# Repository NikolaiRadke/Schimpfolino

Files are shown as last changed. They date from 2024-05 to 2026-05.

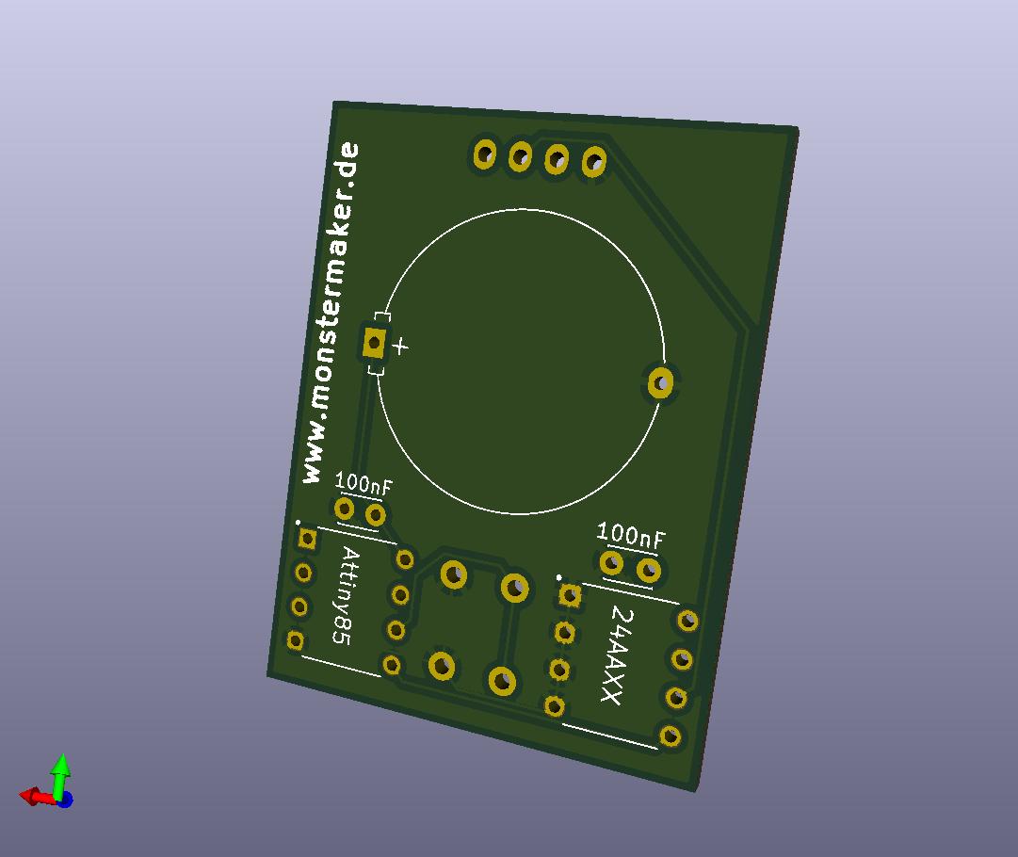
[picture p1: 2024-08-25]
schematics/Schimpfolino_back.jpg

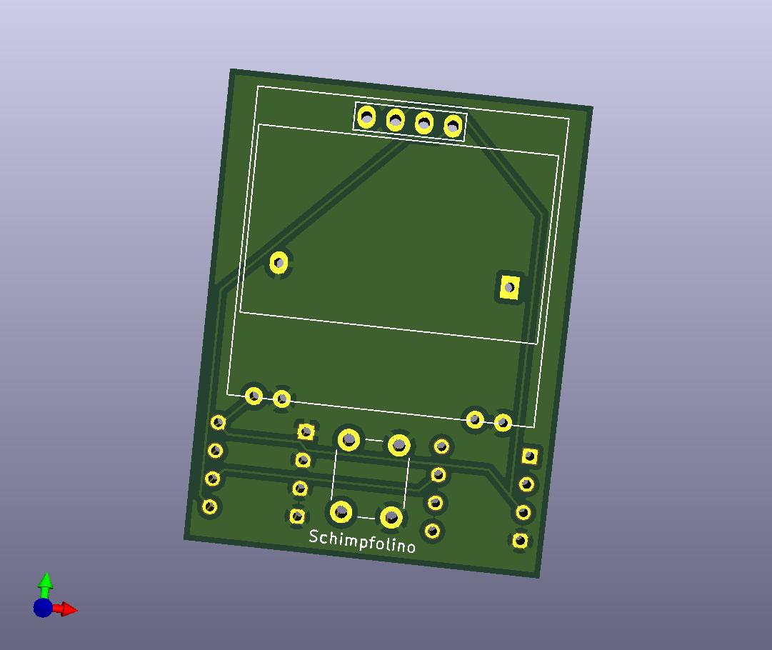
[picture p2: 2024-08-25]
schematics/Schimpfolino_front.jpg

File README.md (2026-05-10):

Schimpfolino

### "Klappriger Blubberfetzen" "Nervendes Riesenungemach" "Windige Pupswindel"  
    
Who doesn't like to be insulted? Schimpfolino is an evil gadget that always has a saying ready. Small, handy, power saving. And completely useless. You need a PCB and some parts listed below. It's easy to build and long lasting for everyday use. Insert battery, press the button and recieve your daily insult!        

*Huch, Englisch? Kann ich nicht. Schnell [hier hin](https://github.com/NikolaiRadke/Schimpfolino/wiki)*.  

Schimpfolino
  
Schimpfolino is a random curse word generator with **12.288.000** possible combinations right now. That should be enough for a while. It's suitable for children (but still evil), maintenance-free and the battery lasts for years. And with the right case, it's an evil monster, like the **Nokolino shaped** case below! Just press the button, receive an insult, after eight seconds it turns off again. That's it. Evil. You can print the case in black! Black is an evil color. It is so evil. It is so evil that it hurts many people that are good!

What's new?  
* **12.04.2026** Updaed ATTinyCore URL.  
    -- More news? See the [newsblog](https://github.com/NikolaiRadke/Schimpfolino/tree/main/NEWS.md).   

### Notes for non-German Schimpfolino makers  
  
The building wiki and the curse words are in German. You need English words? **Contribute!**  

### Prerequisites

Except for the tools and some time, you need:
* Arduino IDE 1.6.6 or higher
* ATTinyCore from Spence Konde  
* Serial terminal software like *CuteCom* (Linux) or *CoolTerm* (Linux/Windows/Mac).  
* Arduino UNO/Nano/Whatever with USB cable
* A breadboard
* Some Dupont wires
* A 10 µF capacitor
* (Optional a 2 kOhm resistor)  
  
And the following hardware:
* Schimpfolino PCB 
* ATtiny25/45/85 (ATtiny25 for V1.4)
* 24AA64 or larger EEPROM (up to 24AA512) - with an ATtiny85, no EERPOM is needed (V1.5).
* 0,96" SDD1306 (V1.0) or 0,96"/1,3" SDD1306/SH1106 I2C display (V1.3)  
* Button 6 x 6 mm, 9,5 mm height
* 2 DIP-8 sockets
* Batteryholder, 20 mm pin spacing
* CR2032 battery
* Double-sided adhesive pad, 25 x 15 x 3 mm
* (Optional 2 100 nF capacitors)  
  
### Content

```
Schimpfolino/
Root directory with some explanation files.  
|
├── case/
|   STL files to 3D print a case. Other kinds of hulls will follow.
|   ├── Boring/
|   |   Plain but smooth case by Michael Kussmaul.
|   ├── CuteVader/
|   |   Cute and evil case by falsanu.
|   └── Nokolino/
|       Standard Nokolino-shaped case.
|
├── python/
|   Schimpfolino as python script.
|
├── schematics/
|   The circuit diagram, PCB renderings and gerber files.
|
└── src/
    Firmware and word files.
    ├── eeprom/
    |   All you need to flash your EEPROM.
    |   ├── eeprom_writer/
    |   |   Arduino sketch to write to your EEPROM.
    |   ├── files/
    |   |   The EEPROM content word lists and the editor.
    |   └── files_new/
    |       EEPROM content vor new version (1.4)
    |
    ├── Schimpfolino/
    |   Standard sketch with libraries used in the Make article. (1.0)
    ├── Schimpfolino_new/ (1.5)
    |   Version for new improvments. Compatible to old version.
    ├── Schimpfolino_nopeeprom/ (1.0)
    |   Sketch for Schimpfolino without EEPROM.
    └── Schimpfolino_nopeeprom_new/ (1.5)
        New version. Compatible to old version.
```

### Let's get started!

Ready? Great! Let's start here: [German wiki](https://github.com/NikolaiRadke/Schimpfolino/wiki).  

## 💙 Support Schimpfolino

Schimpfolino is free and open source. If he saved your day, consider buying me a coffee! ☕




Every contribution helps keep this project alive! 🚀

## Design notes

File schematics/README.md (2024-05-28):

# Schematics

In this folder you can find the circuit diagram **Schimpfolino.pdf**, the PCB renderings and the gerber files to print your PCBs, with the unusual name **gerber.zip**. Upload the file to the PCB dealer of your choice or the dealer you trust and build your own Schimpfolino. Don't hesitate!

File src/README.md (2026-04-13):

# Firmware and tools for Schimpfolino

* **Schimpfolino**: a sketch for use with EEPROM only, for ATtiny45/85. Used in the Make article. For **ATtiny45/85**.   
* **Schimpfolino_noreeprom**: a hybrid sketch for use with or without EEPROM with reduced internal word list. For **ATtiny85 only**. Used in the Make article.  
* **Schimpfolino_new**: new version for new improvments and more supported displays. Compatible to old version. **Recommended**. For **ATtiny25/45/85**.
* **Schimpfolino_noeeprom_new**: Same as above but with a complete compressed internal word list. For **ATtiny85 only**.
* **eeprom/**: folder for files with EEPROM content and writing tool.
  
# Compiling instructions for Schimpfolino

In order to flash your ATtiny with the Schimpfolino sketch, you need the **Arduino-IDE** (1.6.6 or higher), with installed **ATtiny-support** and an **Arduino** connected to your microcontroller.

### Preparing the IDE  
 
1. Open ``` File > Preferences ```.  
2. Find the field ``` Additional Boards Manager URLs ```.  
3. Enter ``` https://drazzy.com/package_drazzy.com_index.json ```.  
4. Press ``` OK ```.  
5. Open ``` Tools > Board > Boards Manager ```.  
6. Select ``` ATTinyCore by Spence Konde ```.  
7. Press ``` Install ```.

> [!NOTE]
> The installation of ATTinyCore often results in an error.  
> See [ATTinyCore GitHub](https://github.com/SpenceKonde/ATTinyCore/blob/v2.0.0-devThis-is-the-head-submit-PRs-against-this/Installation.md) for manual installation Instructions.

### Peparing your Arduino  

1. Connect your Arduino to your system.  
2. Open ``` File > Examples > ArduinoISP > ArduinoISP ```.  
3. Upload the sketch.

### Connecting your ATtiny with the Arduino  

1. Disconnect your Arduino.
2. Connect your ATtiny as seen below.
3. Add the 10 uF capacitor.    
  
ATTINY-ARDUINO  
  
### Burning an ATtiny bootloader  
  
Technically, this process will flash no bootloader, the IDE just sets the fuses. 
  
1. Connect your Arduino to your system again.  
2. Select ``` Tools > Programmer > Arduino as ISP ```.  
   For the **UNO R4** choose ``` Tools > Programmer > Arduino Leo/Micro as ISP (ATmega32U4) ```. 
4. Select ``` Tools > Board > ATTinyCore > ATtiny25/45/85 (No bootloader) ```.
5. Select ``` Tools > Port ``` for the matching port.  
6. Select ``` Tools > B.O.D. Level [...] > B.O.D. Disabled (saves power) ```.
7. Select ``` Tools > Chip > ATtiny85 ``` or ``` Tools > Chip > ATtiny45 ``` or ``` Tools > Chip > ATtiny25 ```.
8. **For V1.X**: Select ``` Tools > millis()/micros() > Disabled (saves flash) ```.
9. Start burning process with ``` Tools > Burn bootloader ```.  

Now you can flash your ATtiny with any sketch you want! But this time, we focus on Schimpfolino.   

### Flashing and configuring Schimpfolino firmware
  
1. Open the Schimpfolino sketch.
2. If you want a bold font, uncomment ``` #// define bold ``` in **oled.h** by removing ``` // ``` (Only V1.X).     
3. Select ``` Sketch > Upload using programmer ``` (IDE 2.X) or press upload button (IDE 1.X and 2.3.3 or newer). 
4. DONE.  

Now you can remove the microcontroller and plug it into the socket of your Schimpfolino.  

## Hints for Linux users  

With some Debain-based distributions like Ubuntu or Mint you might recieve an error while trying to upload your sketch to the ATtiny like  
``` avrdude: ser_open(): can't open device "/dev/ttyUSB0": Permission denied ```.  
This issue can be solved by adding your user to the dialout-group. Open a terminal and type  
``` sudo usermod -a -G dialout $USERNAME ```.  
Enter your password and restart. Now it should work.  

If not: Maybe you are using an **Arduino Nano clone** with **CH340 chip**, the IDE may not find your port. This is because of a conflict with the preinstalled Braille driver. If you don't need it, deinstall the driver with  
``` sudo apt-get remove brltty ```  
and the IDE should find the port after reboot now.

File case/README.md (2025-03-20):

# Case

Schimpfolino is pretty small and handy and works without a hull, fur or case. But if you want a special design, you will find some ideas here:

## Nokolino
Schimpfolino_NokolinoSchimpfolino_Nokolino  

A Nokolino-shaped case for 3D printing.  
* **Schimpfolino_Case_Nokolino.stl** - the case  
* **Schimpfolino_Case_Nokolino_Cover.stl** - the cover

## Boring
Schimpfolino BoringSchimpfolino_BoringSchimpfolino_BoringSchimpfolino_Boring  

A plain but smooth 'boring' case by Michael Kussmaul.
Needs a 30 mm acrylic glass scrreen protection and a no light, 12 mm flat head, stainless or black shell button.  
* **Schimpfolino_Case_Boring.stl** - the case  
* **Schimpfolino_Case_Boring_Cover.stl** - the cover
* **Schimpfolino_Case_Boring_Display_Holder.stl** - the display holder  
* **Schimpfolino_Case_Boring_Inset.stl** - fot the additional screen protection

## Cute Vader
Schimpfolino_NokolinoSchimpfolino_Nokolino  

A small but incredible evil case by Jan Fanslau. GitHub: [falsanu](https://github.com/falsanu)  
* **Schimpfolino_Case_CuteVader.stl** - the case
* **Schimpfolino_Case_CuteVader_Cover.stl** - the cover
   
## More cases and suits will follow. Stay tuned!

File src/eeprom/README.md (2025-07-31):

# Setting up a serial connection and writing to EEPROM

You need:  
* Sketch **eeprom_writer.ino**.
* An Arduino Uno/Nano/Whatever.
* A serial terminal like *CoolTerm* (Linux/Windows/Mac) or *CuteCom* (Linux).

### Connecting your Arduino with the EEPROM

1. Disconnect your Arduino.
2. Connect your Arduino with the EEPROM as seen below. It is an **I2C** connection. If you want to use any other board, connect **SDA** with **pin 5** and **SCL** with **pin 6** of your EEPROM.
   
EEPROM with Arduino

**Wait!** Where is the **pull up resistor**?  
Yes indeed, I2C needs a pull up resistor, **2 kOhm** between **SDA** and **VCC**. But: The Arduino has an internal **20 kOhm** pull up resistor at every I/O pin. These are pulled up with every I2C connections when the standard library **Wire.h** is used. This is not the correct value but works reliable with slow connections. This is a very slow connection. But if you are unsure, add an externel pull up resistor. Schimpfolino's display finally has the missing resistors on board. 
  
For the **UNO R4** (Wifi), the pull up resistor is mandatory!

### Flashing the content

1. Connect the Arduino to your computer.  
2. Open the Schimpfolino writer sketch **eeprom_writer.ino** in the Arduino IDE and upload the sketch. 
3. Start your favorite serial terminal, set to **9600 Baud, 8-N-1** and a **5 ms delay** after each character, no Linefeed (LF) oder Carriage Return (CR). 
4. Open the connection to the port (COM? in Windows, see device manager or IDE | /dev/ttyACM0 for Arduino Uno or /dev/ttyUSB? other Arduinos in Linux)
5. The Arduino will tell you through the serial terminal, what eeprom_writer is doing. Now upload the files **eeprom1.txt** to **eeprom5.txt**. Use folder **files_new** for >= V1.4 or **files** for older versions.  
6. Close the connection and remove the EEPROM.
  
## Structure of eeprom?.txt files

Each file contains a set of words. Each word has **10** characters, spaces are mandatory! Just write them one after another. The EEPROM writing sketch will calculate their number and store both number and words into the EEPROM. The last character of the file has to be a **!**. You need a text editor. An office word processor will not work.  

German **Umlaute** must be converted:  
**ä** -> **[** | **ö** -> **]** | **ü** -> **^** | **ß** -> **_** | **Ä** -> **{** | **Ö** -> **|** | **Ü** -> **}**  
Versions <= V1.3:
**ä** -> **#** | **ö** -> **$** | **ü** -> **%** | **ß** -> **|** | **Ä** -> **&** | **Ö** -> **'** | **Ü** -> **(**
  
There is an (beta) offline editor **eeprom.html** in the files and files_new folders. You can easily add new words or generate a new eeprom?.txt. Umlaute will be converted and spaces and the terminating ! added automatically.

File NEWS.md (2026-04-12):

# Newsblog

## 2026

* **12.04.2026** Updaed ATTinyCore URL.  
* **07.01.2026** Release v1.5 with better text editor and much improved noeeprom version.  

## 2025

* **04.08.2025** Schimpfolino python script added.
* **31.07.2025** Added hints for using the **UNO R4**.  
* **15.05.2025** Firmware **1.X-150525** once again with smaller flash size. The **noeeprom** variants got 5 more words.  
* **08.05.2025** Release **V1.4** with reduced flash size and ATtiny25 support or more words in internal wordlists.  
* **08.05.2025** Firmware **1.4-070525** with more reduced size. **Schimpfolino_new.ino** finaliy fits into an ATtiny25! New EERPOM files needed!  
* **03.05.2025** Firmware **1.X-030525** again with even bigger optimizations: 10 more words for both _noeeprom.ino**.  
* **15.04.2025** Firmware **1.X-150425** with bigger code optimizations: 20 more words for **schimpfolino_noeeprom.ino** and 30 new words for **schimpfolino_noeeprom_new.ino**.  
* **07.04.2025** Firmware **1.X-070425** with code optimizations. One day, it will fit into an ATtiny25... 
* **27.03.2025** Check out Maker Faire Ruhr Dortmund with Schimpfolino-Kits available at the heise shop an **Schimpferator**, the XXL-Schimpfolino!   
* **30.03.2025** Added new 'CuteVader' case by [falsanu](https://github.com/falsanu)     
* **13.03.2025** Release **V1.3** with a bugfix and improvements.  
* **13.03.2025** Firmware **1.01-130325** with fix for long words and **1.3-130325** with fix and now full 1.3" support.   
* **20.02.2025** Updated **eeprom_writer** with check for last written word.  
* **16.01.2025** Release **V1.2.2** with final text centering method.  
* **16.01.2025** Firmware **1.01-160225** and **1.22-160125** with, finally, perfect text centering :-)  
  
## 2024

* **28.12.2024** Release **V1.2.1** with the new case and a fix for SH1106 displays.  
* **28.12.2024** Added new 'boring' but smooth case by [Michael Kussmaul](https://github.com/kusmi).  
* **24.12.2024** Firmware **1.X-241224** Increased OLED init time for more compatibility.   
* **07.11.2024** Firmware **1.2-071124** with external wordlist for **Schimpfolino_nooeeprom_new.ino**. 
* **05.11.2024** Firmware **1.X-051124** with fixed text centering. Finally!      
* **30.10.2024** Firmware **1.2-391024** with heavy shrunk (and crippled) libraries.    
* **29.10.2024** Release **V1.2** with enough new features to justify it.   
* **29.10.2024** **V1.2** with optional bold font. **1.2-291024**.  
* **26.10.2024** **V1.1** now with full SH1106 support. **1.1-271024**.    
* **26.10.2024** **1.03-261024** now supports SH1106 displays. Thanks to Sebastian Völkel.  
* **21.10.2024** Firmware **1.02-201024**. Switched to Tiny-I2C library and freed 600 bytes. Schimpfolino_new_eeprom now has 5 x 15 more words.  
* **19.10.2024** Firmware **1.0x-191024**. Fixed the noeeprom bug and removed the workaround. Finally. Pew.  
* **18.10.2024** Firmware **1.01-181024** for the *new* versions is working now. **Schimpfolino_noeeprom_new.ino** got 5 x 5 new words.  
* **17.10.2024** Release **V1.0M fixed**: important for Schimpfolino_noeeprom.ino **with** EEPROM and small further optimizations.  
* **16.10.2024** Small optimization and **Schimpfolino_noeeprom.ino** is working correctly again! Pew! **1.0x-161024**.  
* **11.10.2024** Better helping variable handling. Won 16 bytes! Worth an update? Yes, of course! **1.01-111024** and **1.0-111024**.  
* **10.10.2024** New sketches added. **1.01-101024** with removed millis(): 182 bytes saved. Old versions are for the Make article but the new 1.01 versions are compatible.  
* **19.08.2024** Release **V1.0M** - (M for Make Magazie) Schimpfolino seems to be finished! Well... for now ;-)   
* **05.08.2024** Big Umlaute are supported. **1.0-050924**.
* **24.08.2024** Slightly flash usage improvements. **1.0-290824**.  
* **24.08.2024** Schimpfolino is now using a **24AAXX** EEPROM to save more power. No changes in the code needed.  
* **10.08.2024** Code of Conduct was added.
* **07.08.2024** Final PCB design was uploaded.  
* **13.07.2024** Optimized power management and prepared firmware for new coming board. **1.0-130724**.
* **10.07.2024** Halfed idle power draw. **1.0-100724**.  
* **10.07.2024** Better random numnner generator. Small and reliable.
* **09.07.2024** Better individual random seed. **1.0-090724**.
* **05.07.2024** Set open ports to INPUT_PULLUP to prevent floating. **1.0-050724**.
* **27.06.2024** eeprom_writer now waits for EEPROM connection.
* **26.06.2024** Added hints to pull up resistors when using the EEPROM with Arduino.  
* **18.06.2024** The **EEPROM Editor** has been improved.  
* **16.06.2024** An **EEPROM Editor** for the word list files was added.  
* **14.06.2024** Optimized code and finished **Schimpfolino_noeeprom**. Both are **1.0-140624** now.
* **13.06.2024** Added **TODO.md** - everyone needs a ToDo list!  
* **13.06.2024** (Slighty) better text centering and higher display contrast. **1.0-130624**. 
* **12.06.2024** Big SSD1306 rework. Version is now **1.0-120624**. 
* **11.06.2024** **Schimpfolino_wire** is now ***Schimpfolino**. TinyWireM is not needed anymore.
* **07.06.2024** Added alternative firmware **Schimpfolino_wire** with version **1.0-070624**  
* **07.06.2024** Updated **Schimpfolino** to **1.0-070624** with small libary cleanups.  
* **07.06.2024** Switched to ATTinyCore. It's much more modern, builds smaller binaries and has tons of features.  
* **29.05.2024** Schimpfolino got his first release!  
* **28.05.2024** Finished the German wiki! Schimpfolino is ready to release.
* **26.05.2024** Finished the last README files! The repository is almost ready. 
* **25.05.2024** The case cover fits perfectly!
* **24.05.2024** New Nokolino shaped case model.
* **23.05.2024** Renamed source files. The main file with eeprom ist now **Schimpfolino.ino**.
* **22.05.2024** Reworked EEPROM content structure and adjusted text centering. **1.0-220524**.  
* **20.05.2024** schimpfolino_eeprom: text is now centered. Version is **1.0-200524**.  
* **17.05.2024** Opened the Schimpfolino repository.
* **17.05.2024** Latest release of **schimpfolino_eeprom** to **1.0-090524**.
* **17.05.2024** Latest release of **schimpfolino** to **1.0-050524**.
* **17.05.2024** Latest release of **eeprom-writer** to **1.0-090524**.

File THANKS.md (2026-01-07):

# Thanks

These people helped me with Schimpfolino:  
  
 - **Elise Lindner** - finding funny words.
 - **Elisabeth Seidl** - graphics. 
 - **[falsanu](https://github.com/falsanu)** - the 'CuteVader' case, filament and some ideas.
 - **Marcus Hansson** - the great articles in the German Make Magazin.
 - **[MDecker](https://github.com/MDecker-MobileComputing)** - spelling corrections.
 - **Sebastian Völke** - SH1106 support and bold font.
 - **Birger Töpelmann** - wordlist ideas.
 - **Michael Kussmaul** - solving an annoying display issue and the 'Boring' case.
 - **Tilman Beck** - hints für using the UNO R4.
 - **Markus Fölling** - better EEPROM files editor.  
 - **Make Magazin** - publishing three articles.  
  
Used ressources:  
  
- **Arduino IDE 2.3.4** - [Arduino](http://www.arduino.cc)  
- **ATTinyCore** - [GitHub](https://github.com/SpenceKonde/ATTinyCore)
- **SD1306_nimimal library** - [GitHub](https://github.com/kirknorthrop/SSD1306_minimal)
- **Tiny-I2C library** (V1.X) - [GitHub](https://github.com/technoblogy/tiny-i2c)  
- **CuteCom 0.30.3** - [Sourceforge](https://cutecom.sourceforge.net/)
- **KiCad 8.0** - [KiCad](https://www.kicad.org)
- **Tinkercad** - [Tinkercad](https://www.tinkercad.com)
- **Cura 5.7.1** - [UltiMaker](https://ultimaker.com/de/software/ultimaker-cura)
- **Inkscape 1.1** - [Inkscape](https://inkscape.org)
- **Gimp 2.10.32** - [Gimp](https://www.gimp.org)
- **Fritzing 0.9.6** - [Fritzing](https://fritzing.org)  
- **ChatGPT** - [OpenAI](https://chatopenai.de/)

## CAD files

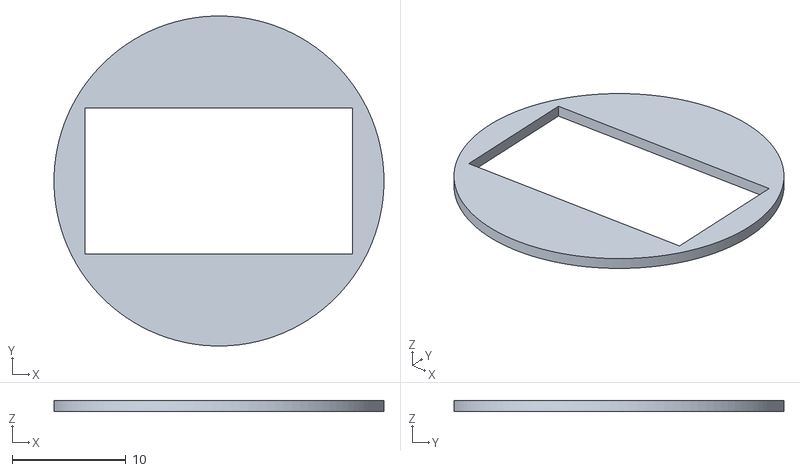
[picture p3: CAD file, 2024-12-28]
case/Boring/Schimpfolino_Boring_Inset.stl
29.0 x 29.0 x 1.00

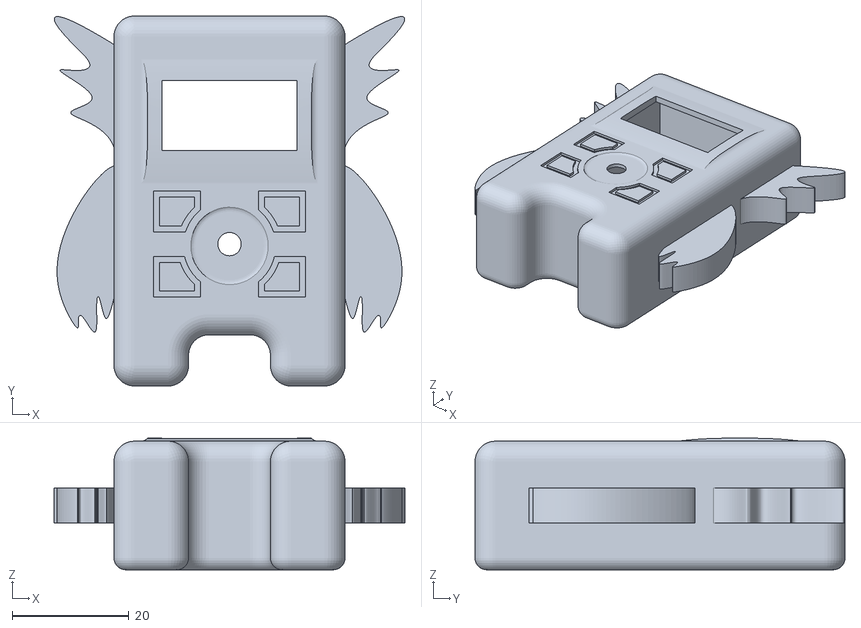
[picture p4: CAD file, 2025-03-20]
case/CuteVader/Schimpfolino_Case_CuteVader.stl
59.9 x 63.3 x 22.5

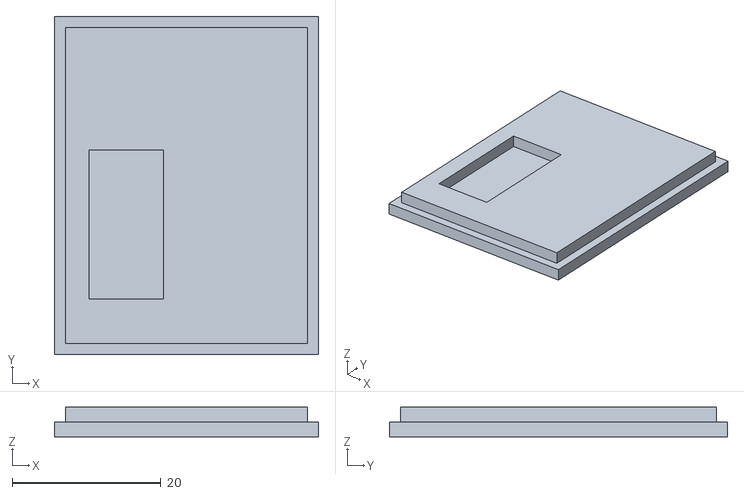
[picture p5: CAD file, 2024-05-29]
case/Nokolino/Schimpfolino_Case_Nokolino_Cover.stl
35.5 x 45.5 x 4.00

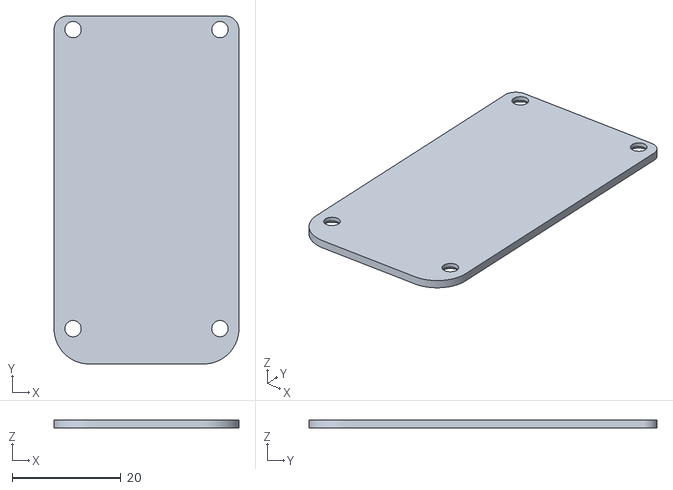
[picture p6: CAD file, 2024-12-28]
case/Boring/Schimpfolino_Boring_Cover.stl
34.0 x 64.0 x 1.50

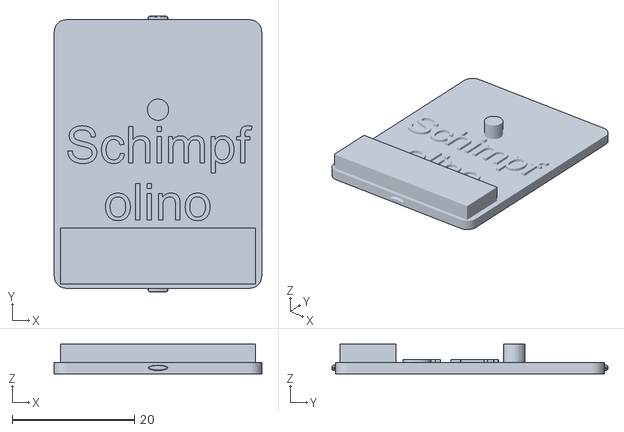
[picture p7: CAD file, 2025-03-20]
case/CuteVader/Schimpfolino_Case_CuteVader_Cover.stl
34.0 x 45.2 x 4.90

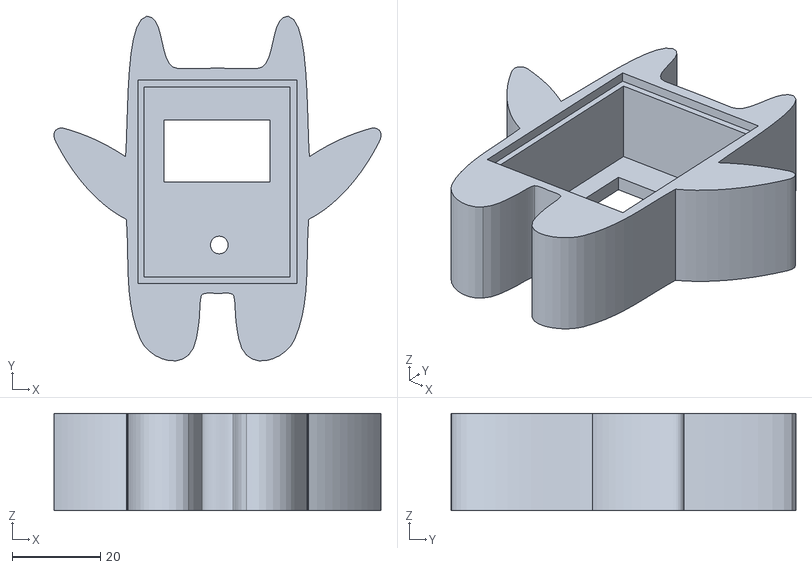
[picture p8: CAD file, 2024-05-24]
case/Nokolino/Schimpfolino_Case_Nokolino.stl
74.0 x 78.0 x 22.0

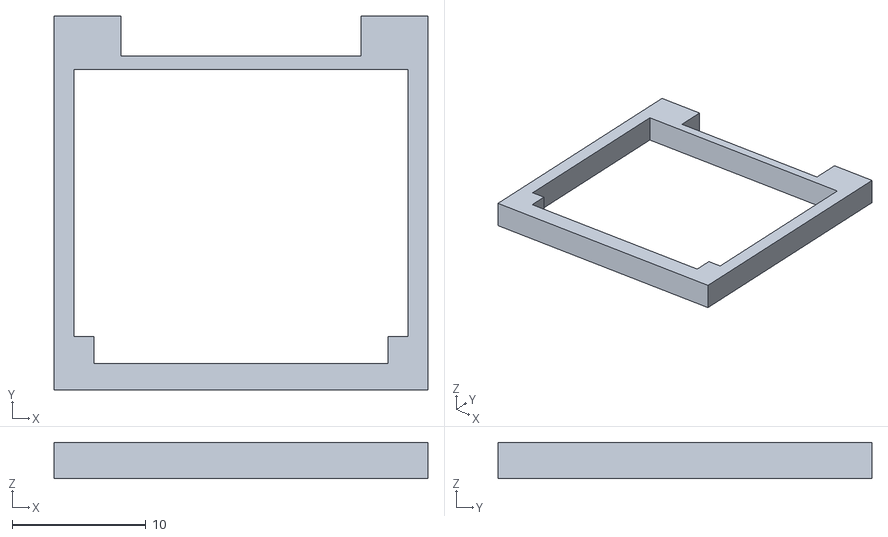
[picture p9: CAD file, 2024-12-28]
case/Boring/Schimpfolino_Boring_Display_Holder.stl
28.0 x 28.0 x 2.70

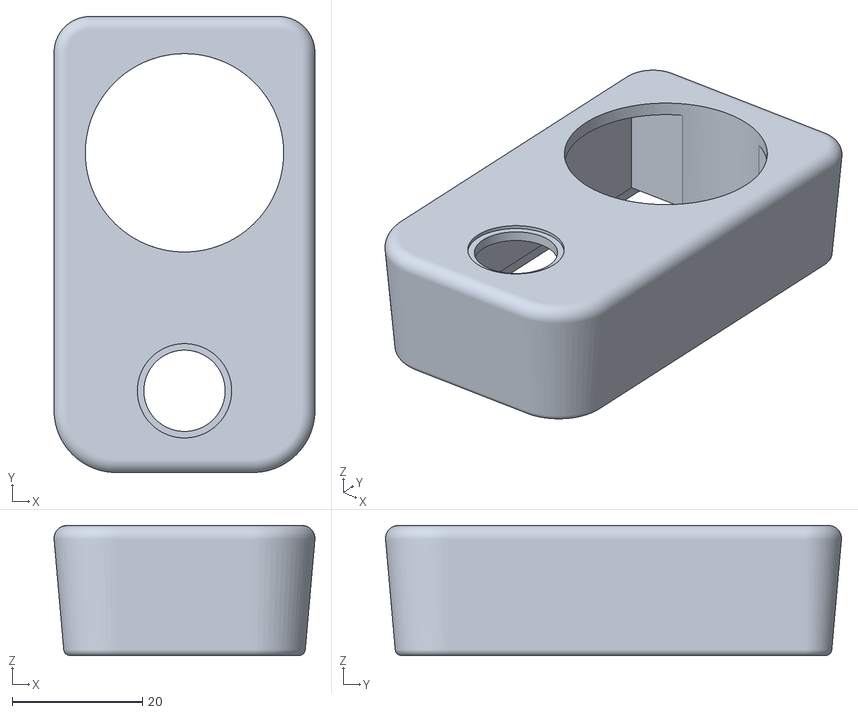
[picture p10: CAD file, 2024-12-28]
case/Boring/Schimpfolino_Case_Boring.stl
40.1 x 70.1 x 20.0

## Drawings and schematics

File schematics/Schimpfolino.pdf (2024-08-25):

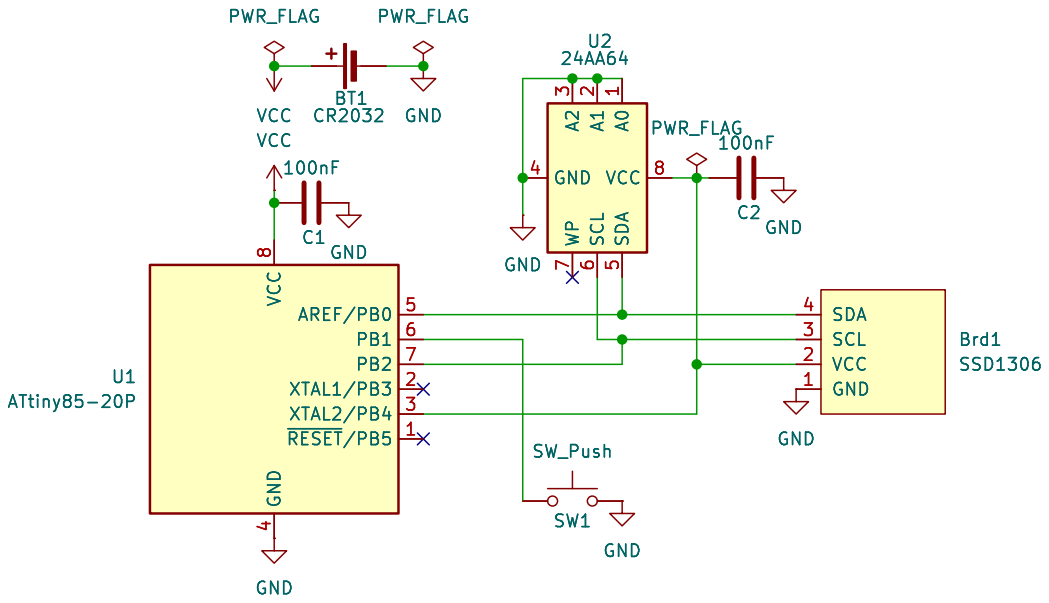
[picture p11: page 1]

7 VCC 8 Brd1 SSD1306 GND 1 VCC 2 SCL 3 SDA 4 GND GND

File: Schimpfolino.kicad_sch Sheet: / www.monstermaker.de GND

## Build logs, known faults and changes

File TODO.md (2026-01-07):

# TODO

* More case design files
* Other kind of suits

## In progress

* Finding a distributor for the PCB or the hole kit

## Done

* ATtiny25 support
* Fitting the complete word list the no-eeprom version
* Any code optimization i can find 
* Update to final V1.0
* HTML-based EEPROM text file editor
* First release
* Fist article for the Make Magazine
* Second article for the Make Magazine
* Third article for the Make Magazine
* At least one additional case design
* Support for SH1106 display types
   
## One day

* English version
* Other languages

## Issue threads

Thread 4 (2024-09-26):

Typo in file "eeprom5.txt"

MDecker-MobileComputing, 2024-09-26:
Word "Folikel" in file `eeprom5.txt` should be replace with "follikel":

* Like the other words in this file, the word should start with a lower case letter.
* Right spelling with two "L" after the "O": [Follikel](https://www.duden.de/rechtschreibung/Follikel)

NikolaiRadke, 2024-09-26:
Thanks!!

Closed 2024-09-26.

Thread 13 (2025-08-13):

eeprom_writer.ino  -  Invalid device signature in Arduino

MagicSven81, 2025-08-13:
i get the following message when i try to upload the "eeprom_writer" sketch via Arduino Uno to my 24LC64

What did i make wrong?

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

NikolaiRadke, 2025-08-14:
Cool!
Enjoy your insults :-)

Closed 2025-08-14.

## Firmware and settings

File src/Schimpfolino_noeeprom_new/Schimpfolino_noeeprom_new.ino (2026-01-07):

/*  
    Schimpfolino V1.5 07.01.2026 - Nikolai Radke
    https://www.monstermaker.de
    Optimized version with point-terminated strings and complete word list

    Sketch for the insulting gadget | With or without additional 24AAXXX EEPROM
    For ATtiny85 only - set to 8 MHz | B.O.D disabled | No bootloader | No millis()
    Remember to burn the "bootloader" (IDE is setting fuses) first!

    Flash usage: 8.040 bytes (IDE 2.3.7 | ATTinyCore 1.5.2 | Linux X86_64 | ATtiny85)
    Power:       1.6 mA (display on, no EEPROM) | ~ 200 nA (sleep)

    Umlaute have to be converted (UTF-8):
    ä -> [ | ö -> ] | ü -> ^ | ß -> _ | Ä -> { | Ö -> | | Ü -> }

    Wiring:
                         +-\/-+
    RST          - PB5  1|    |8  VCC - Battery
    Free         - PB3  2|    |7  PB2 - SCL
    Devices VCC  - PB4  3|    |6  PB1 - Button -> GND
    GND          - GND  4|    |5  PB0 - SDA
                         +----+
*/

#include <util/delay.h>                          // Needs less flash memory than delay()
#include "TinyI2CMaster.h"                       // I2C communication with display and EEPROM. Very tight library!
#include "oled.h"                                // OLED display library for SSD1306 and SH1106
#include "Schimpfolino_wordlist.h"               // Optimized wordlist with backslash-terminated strings

// Hardware
#define  BUTTON   PB1                            // Button pin
#define  DEVICES  PB4                            // External devices power pin

// Variables
const char *field;                               // Pointer to one of the character arrays
uint8_t  chars = 0;                              // Number of characters in the word | Global
uint16_t addresses[5] = {160, 160, 160, 160, 160}; // Each list has 160 words - overwritten if EEPROM present
char     wordbuffer[20];                         // Buffer for read words
bool     eeprom = false;                         // No EEPROM used -> auto detect

volatile bool awake = false;                     // Stay awake when button is pressed

int main(void) {                                 
  // Power saving
  ADCSRA &= ~(1 << ADEN);                        // Switch ADC off | Saves 270 uA
  MCUCR = (1 << SM1) | (0 << SM0);               // Always deepest sleep mode (Power-down)

  // Port setup
  DDRB = (1 << DEVICES) | (1 << SDA) | (1 << SCL); // Set PB4 to OUTPUT to power up display and EEPROM | SDA and SCL for I2C
  PORTB = 0x3F;                                  // Set output ports to HIGH and input ports to INPUT_PULLUP to prevent floating

  // Hardware pin and watchdog interrupt
  cli();                                         // Stop all interrupts. An interrupt can ruin the timed sequence
  GIMSK |= (1 << PCIE);                          // Turn on pin change interrupt
  PCMSK |= (1 << PCINT1);                        // Turn on interrupt on PB1 button
  MCUSR &= ~(1 << WDRF);                         // No watchdog reset 
  WDTCR |= (1 << WDCE) | (1 << WDE);             // Watchdog change enable
  WDTCR = (1 << WDP0) | (1 << WDP3);             // Set prescaler to 8 s
  sei();                                         // Start interrupts

  // Init I2C
  TinyI2C.init();                                // Start I2C

  // Look for EEPROM and read wordlist addresses if available
  if (TinyI2C.start(0x50, 0)) {                  // Look for 24LCXX EEPROM at 0x50
    eeprom = true;                               // if available, set EEPROM flag
    for (uint8_t wlist = 0; wlist < 5; ++ wlist) // Read numbers of 5 wordlists
      addresses[wlist] = (read_eeprom(wlist << 1) << 8) | read_eeprom((wlist << 1) + 1); // Write word numbers to array
  }

  // Randomize number generator
  PORTB &= ~(1 << DEVICES);                      // Devices off
  sleep();                                       // Sleep until button is pressed to "turn on"
  TCCR0A = 0x00;                                 // Set timer 0 to normal mode
  TCCR0B = (1 << CS00);                          // Set prescaler to 1 to start the timer
  while (!(PINB & (1 << BUTTON)));               // Wait until button is released
  randomSeed(TCNT0);                             // Get a time count as seed

  // Main routine | Runs after waking up
  for(;;) {
    // Init Display
    PORTB |= (1 << DEVICES);                     // Devices on
    PRR |= (1 << PRTIM0) | (1 << PRTIM1);        // Both timers are not needed anymore | Saves 100 uA when active
    Oled_init();                                 // Connect and start OLED via I2C

    // Display swearwords until timeout
    while(awake) {                               // Wait 8.5 seconds timeout
      Oled_clear();                              // Clear display buffer

      // First word
      field = data1;                             // Pointer to first array
      get_swearword(random(0, addresses[0]));    // Read first word from EEPROM or wordlist
      uint8_t genus = random(0, 3);              // Set word genus
      if (genus) {                               // Check if not female
        wordbuffer[chars] = 48 + genus;          // If male, add "r", if neutrum, add "s" to buffer
        ++ chars;                                // Increase number of characters
      } 
      write_swearword(2);                        // Write first word in the first line

      // Second word first part
      uint16_t list = 0;                         // Set start address for array
      if (eeprom) list = addresses[0];           // Set start address for EEPROM
      field = data2;                             // Pointer to second array
      get_swearword(random(list, addresses[1])); // Read first part of second word 
        
      // Second word second part
      if (eeprom) list = addresses[genus + 1];   // Set start address for EEPROM
      field = data3;                             // Pointer to female array
      if (genus == 1) field = data4;             // Pointer to male array
      if (genus == 2) field = data5;             // Pointer to neutrum array
      get_swearword(random(list, addresses[genus + 2])); // Read second part of second word
      write_swearword(4);                        // Write second word in second line
        
      // Wait for button and sleep 8s
      _delay_ms(500);                            // Debounce button
      awake = false;                             // Set to sleep
      WDTCR |= (1 << WDIE);                      // Set watchdog interrupt
      sleep();                                   // Sleep 8 s or wake when button is pressed
      WDTCR &= ~(1 << WDIE);                     // Stop watchdog interrupt
    } 

    // Go to sleep after 8s seconds if button is not pressed before                           
    Oled_sendCommand(0xAE);                      // Display off and sleep (old boards)
    PORTB &= ~(1 << DEVICES);                    // Devices off
    sleep();                                     // Sleep until button is pressed
  }
}

// Functions
void get_swearword(uint16_t address) {           // Fetch characters from Flash or EEPROM
  if (eeprom) {                                  // EEPROM mode: 10-byte fixed-length words
    address *= 10;                               // Adjust address
    for (uint8_t i = 0; i < 10; ++ i) {          // Read 10 characters
      char c = read_eeprom(address + i + 10);    // Mit Offset 10
      if (c != 32) wordbuffer[chars ++] = c - 65; // 32=Space, 65=A 
    }
  } else {                                       // Flash mode: point-terminated strings 
    uint16_t pos = 0;                            // Start beginning
    while (address) {                            // Find word position in array
      if (pgm_read_byte(&field[pos++]) == 46) address--; // Look for point
    }
    char c;
    while ((c = pgm_read_byte(&field[pos++])) != 46) // Look for next point
      wordbuffer[chars ++] = c - 65;             // Store character
  }
}

void write_swearword(uint8_t line) {             // Write centered word
  uint8_t x = (128 - (chars * 7)) >> 1;          // Calculate centering
  if (chars > 17) x = (128 - (chars * 6)) >> 1;  // Modify for very long words
  Oled_cursorTo(x, line);                        // Set cursor to selected line
  for (x = 0; x < chars; ++ x)                   // Print the characters...
    Oled_printChar(wordbuffer[x]);               // ...from buffer
  chars = 0;                                     // Set number of characters back to 0 
}

uint8_t read_eeprom(uint16_t e_address) {        // Read from EEPROM
  TinyI2C.start(0x50, 0);                        // Open connection to I2C-address 0x50 in write mode
  TinyI2C.write(e_address >> 8);                 // Send the MSB (Most Significant Byte) of the memory address
  TinyI2C.write(e_address & 0xFF);               // Send the LSB (Least Significant Byte) of the memory address
  TinyI2C.start(0x50, 1);                        // Restart connection for reading one byte
  return TinyI2C.read();                         // Read and return byte
}

void sleep() {
  MCUCR |= (1 << SE);                            // Set SE (Sleep Enable) bit
  __asm__ __volatile__ ("sleep" "\n\t" ::);      // Sleep now!!
  MCUCR &= ~(1 << SE);                           // Clear SE bit
}

ISR(PCINT0_vect) {                               // Interrupt routine for pin change 
  awake = true;                                  // Set awake flag when button is pressed
}

ISR(WDT_vect) {}                                 // Interrupt routine for watchdog. Unused but mandatory

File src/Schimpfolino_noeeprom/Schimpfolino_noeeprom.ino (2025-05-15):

/*  
    Schimpfolino V1.01 15.05.2025 - Nikolai Radke
    https://www.monstermaker.de

    Sketch for the insulting gadget | With or without additional 24AAXXX EEPROM
    For ATtiny85 only - set to 8 MHz | B.O.D disabled | No bootloader
    Remember to burn the "bootloader" (IDE is setting fuses) first!

    Flash usage: 8.182 bytes (IDE 2.3.6 | ATTinyCore 1.5.2 | Linux X86_64 | ATtiny85)
    Power:       1.6 mA (display on, no EEPROM) | ~ 200 nA (sleep)

    Umlaute have to be converted (UTF-8):
    ä -> # | ö -> $ | ü -> % | ß -> * | Ä -> & | Ö -> ' | Ü -> (
    Last character of a wordlist is "!" 

    Wiring:
                         +-\/-+
    RST          - PB5  1|    |8  VCC - Battery
    Free         - PB3  2|    |7  PB2 - SCL
    Devices VCC  - PB4  3|    |6  PB1 - Button -> GND
    GND          - GND  4|    |5  PB0 - SDA
                         +----+
*/

#include <avr/sleep.h>                           // Used for deep sleep
#include <util/delay.h>                          // Needs less flash memory than delay()
#include "SSD1306_minimal.h"                     // Modified library!
#include <Wire.h>                                // I2C communication with display and EEPROM

// Hardware
#define  BUTTON   PB1                            // Button pin
#define  DEVICES  PB4                            // External devices power pin

// Wordlist arrays - a single array can hold only 4000 bytes | Used if no EEPROM present | 5 x 97 words = 4850 bytes
const char data1[] PROGMEM = {"Dumpfe    Staubige  Miefende  Stinkende Gammlige  Hinkende  Winzige   Popelige  Nasse     Furzende  Rostige   Hohle     Siffige   Miese     Krumme    Klapprige Trockene  Haarige   Uralte    Grunzende SchreiendeMeckernde Nervende  Sabbernde Triefende Modrige   Lumpige   Lausige   Sinnlose  Olle      Unn$tige  Dampfende Ledrige   Einarmige Leere     L#stige   Heulende  Pickelige Faule     Ranzige   Tr%be     Dralle    Blanke    Gierige   Tranige   Wackelnde Torkelnde W%ste     Fischige  Beknackte Modrige   VerkorksteHeimliche L$chrige  Brockige  Plumpe    Tattrige  Ratternde SchmutzigeLiderlicheD$sige    Prollige  Fiese     Dr$ge     Muffige   M%ffelnde Peinliche N$rgelnde Fettige   Zahnlose  Freche    Sch#bige  Piefige   Gummige   Labbrige  Patzige   Pelzige   Reudige   Pekige    M%rbe     Harzige   Lahme     Mickrige  Br#sige   Zottelige Gelbliche Knorrige  Salzige   Schrille  Dusselige Windige   Grausige  Gr#sslicheGrobe     Spackige  Kauzige   Flachsige "};
const char data2[] PROGMEM = {"Stampf    Wabbel    Pups      Schmalz   Schmier   Hack      Zement    Spuck     Stachel   Keller    Laber     Stock     Runzel    Schrumpf  Ekel      Schnodder Matsch    Wurm      Eiter     Speck     Mist      Klotz     W%rg      Lumpen    Schleim   Wurst     Doof      Brat      Schwamm   Kratz     Grotten   Kriech    Gift      Schlabber Reier     G$bel     Knatter   Kleb      Schmadder Grind     Labber    Luft      Massen    Schimmel  Mini      Ochsen    Problem   Quassel   Schnaps   Saft      Fummel    Friemel   Zappel    Tropf     Pluntsch  Sumpf     Hecken    Grab      Schwitz   Schnarch  Schleich  Schluff   Fl$ten    Holz      Kreisch   Dulli     Luschen   Gammel    Alt$l     R$chel    Glibber   Lach      Krach     Knick     Quetsch   Quatsch   Quietsch  Knautsch  T%mpel    Teich     Knatter   Sauf      Pipi      Struller  Gr#ten    Nasen     Pech      Leier     Reier     Bl$d      Schorf    Sabbel    Quengel   Bananen   Unsinns   Plunsch   Frust     "};
const char data3[] PROGMEM = {"suppe     socke     bombe     boulette  schwarte  warze     beule     pest      pflaume   r%be      geige     ratte     krankheit wunde     oma       knolle    stulle    liese     brut      henne     zwiebel   bude      kiste     braut     leuchte   kr$te     nuss      spinne    grube     toilette  krake     pf%tze    backe     bratsche  klatsche  nudel     knolle    t%te      nase      made      tonne     krampe    b%rste    windel    semmel    haxe      gr#fin    schleuder zierde    kr#he     latte     niete     rassel    assel     torte     galle     latsche   schrulle  kanone    blase     pelle     trine     queen     zecke     praline   magt      pracht    fritte    so*e      larve     murmel    hexe      pampe     sirene    dr%se     klette    petze     brumme    glatze    qualle    natter    kralle    ziege     gr%tze    s%lze     nulpe     wampe     frikadelleflunder   trulla    zichte    uschi     kuh       pappe     hupe      tr$te     schabe    "};
const char data4[] PROGMEM = {"busch     fink      nagel     bammel    klopper   tentakel  br#gen    schlumpf  husten    ersatz    haufen    beutel    kn$del    r%ssel    hintern   eimer     pickel    stumpf    k#se      molch     kohl      gnubbel   sack      hansel    puller    alptraum  kasten    kopf      beutel    bewohner  kuchen    freund    nascher   opa       rotz      klumpen   peter     hupsi     bengel    kollege   fleck     l$ffel    lurch     hobel     spaten    pudel     rettich   rinnstein unfall    lappen    k%bel     mops      pfosten   zwerg     pudding   nuckel    putzer    l%mmel    baron     mop       besen     feudel    br#gen    bolzen    pilz      stiefel   k$ter     gulli     pfropf    schrank   k$nig     pott      paddel    rinnstein zinken    haken     witz      buckel    knecht    fan       schmand   klops     gauner    lulli     graupe    pimpf     kasper    spross    teufel    hammel    bock      schmodder pr%gel    spie*er   aal       groschen  geist     "};
const char data5[] PROGMEM = {"sekret    balg      blag      monster   gel$t     imitat    skelett   ding      unding    auge      brot      deo       insekt    bier      mus       ende      futter    gew#chs   produkt   ger$ll    bonbon    furunkel  paket     virus     desaster  st%ck     fass      zeug      ferkel    ei        gewitter  hormon    experimentgulasch   schnitzel fell      theater   schauspielbaby      spielzeug gel       donutloch gelee     gelumpe   zeug      schaf     molek%l   gew%rz    gespenst  gespinnst mittel    geschnetz organ     risotto   vieh      ges#*     gez%cht   ekzem     moped     ger%mpel  hirn      gef#*     wachstum  moloch    rinnsaal  gemenge   opossum   frettchen h#hnchen  plankton  untier    unget%m   gebr#u    fondue    beispiel  elend     leid      gift      verderben ungl%ck   drama     trauma    versagen  fiasko    dilemma   debakel   tabu      ger%cht   hindernis dingdong  dingsbums gewicht   abwasser  abbild    modell    gem#lde   brett     "};
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

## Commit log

2024-05-16 First push
    [Schimpfolino.scad, Schimpfolino.stl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]
2024-05-22 Reworked eeprom structure and text centering
    [Schimpfolino_eeprom.ino]
2024-05-23 Clean up
    [Schimpfolino.scad, Schimpfolino.stl, Schimpfolino_Monster.stl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]
2024-05-24 New case models
    [Schimpfolino_Monster.stl, schimpfolino_case_nikolino.stl, schimpfolino_case_nokolino_cover.stl]
2024-05-25 Finished case cover
    [schimpfolino_case_nokolino_cover.stl]
2024-05-29 New case cover
    [schimpfolino_case_nokolino.stl, schimpfolino_case_nokolino_cover.stl]
2024-06-07 Switched to ATTinyCore by Spence Konde.
2024-06-12 Moved completely to wire.h
2024-06-27 write_eeprom now waits for inserted EEPROM
2024-07-03 Reworked schematics
2024-07-05 Set open ports to INPUT_PULLUP to prevent floating
    [Schimpfolino.ino, Schimpfolino_noeeprom.ino]
2024-07-10 Halfed idle power draw
2024-07-13 Reworked power management V1.0-130724
    [Schimpfolino.ino, Schimpfolino_noeeprom.ino]
2024-07-27 Corrected SDA in sketch wiring diagram
    [Schimpfolino.ino, Schimpfolino_noeeprom.ino]
2024-08-07 New board and V1.0 release!
2024-08-25 Switched to 24AAXXX EEPROM
2024-10-11 Found a small error in the comments
    [Schimpfolino.ino, Schimpfolino_new.ino, Schimpfolino_noeeprom.ino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]
2024-10-12 Spelling corrections in comments
    [Schimpfolino.ino, Schimpfolino_new.ino, Schimpfolino_noeeprom.ino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]
2024-10-16 Corrections and workaround for Schimpfolino_noeeprom.ino
    [Schimpfolino.ino, Schimpfolino_new.ino, Schimpfolino_noeeprom.ino]
2024-10-17 New V1.01 versions are not working correct
    [Schimpfolino_new.ino, Schimpfolino_noeeprom.ino, Schimpfolino_noeeprom_new.ino]
2024-10-19 Fixed the noeeprom-bug and removed the workaround
    [Schimpfolino_noeeprom.ino, Schimpfolino_noeeprom_new.ino]
2024-11-05 Fixed bad text centering
    [Schimpfolino.ino, Schimpfolino_new.ino, Schimpfolino_noeeprom.ino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]
2024-12-20 Update oled.cpp
    Fixed glitch in character ü
    [oled.cpp]
2024-12-28 New 'boring' case
    [Schimpfolino_Boring_Case Lid.stl, Schimpfolino_Boring_Case.stl, Schimpfolino_Boring_Display_Holder.stl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]
2025-03-13 Fix for long words and V1.3 full 1,3'' support
    [Schimpfolino.ino, Schimpfolino_new.ino, Schimpfolino_noeeprom.ino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]
2025-03-14 Spelling corrections in the comments
    [Schimpfolino_noeeprom.ino, Schimpfolino_noeeprom_new.ino]
2025-03-20 New Cute Vader case
    [Schimpfolino_Case_CuteVader.stl, Schimpfolino_Case_CuteVader_Cover.stl]
2025-05-08 Fixed small bug with bold font ä
    [oled.cpp]
